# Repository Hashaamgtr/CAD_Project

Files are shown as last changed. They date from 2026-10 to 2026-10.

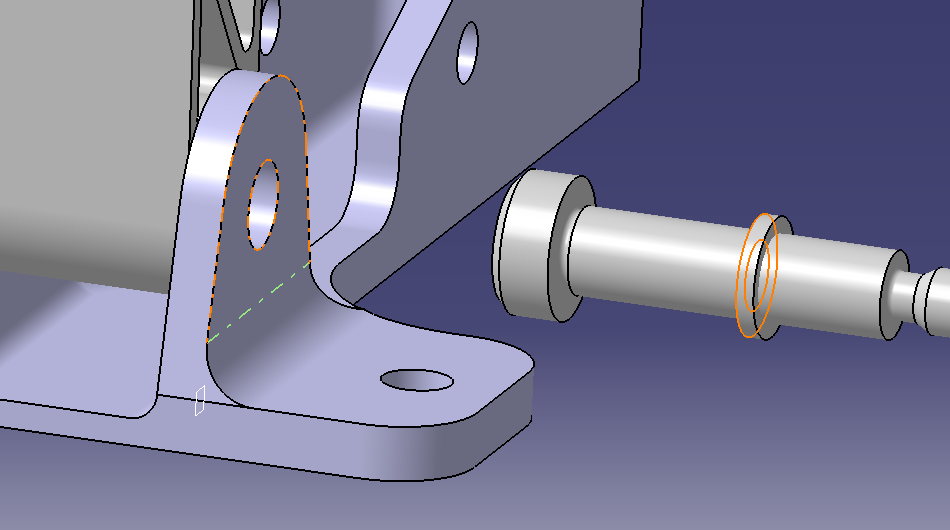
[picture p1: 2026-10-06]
review/05_CATIA_V5_2026_ASSembly_Design/image26.png

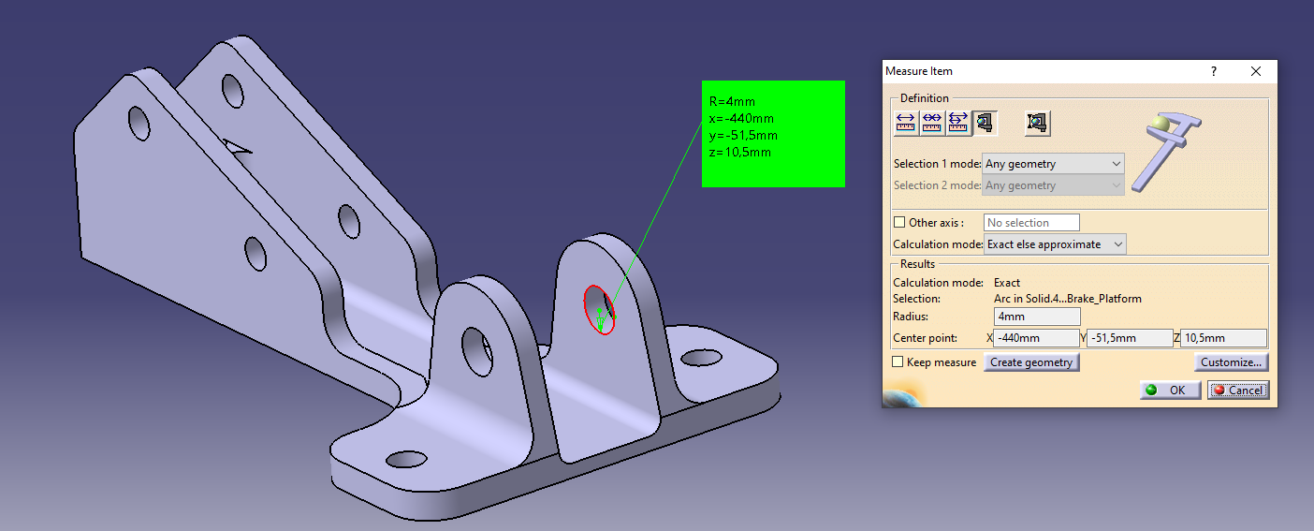
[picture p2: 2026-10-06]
review/05_CATIA_V5_2026_ASSembly_Design/image18.png

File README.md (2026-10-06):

# CATIA brake pedal project

This repository contains the complete unpacked CATIA V5 brake-pedal project handoff plus automation for Presentation 05 and Presentation 06.

## One-click completion on the CATIA Windows machine

Double-click:

`COMPLETE_PROJECT.bat`

The runner:

1. starts CATIA V5 automatically when possible,
2. fixes live-part internal PartNumbers,
3. repairs `Pedal_Body.CATPart` to reference-equivalent geometry while preserving the original live model as a backup,
4. generates `Brake_Pedal_Assembly_05.CATProduct`,
5. generates the full Presentation 06 `Brake_Pedal_Assembly.CATProduct` with the required 45 BOM instances,
6. validates parts/update state/BOM counts,
7. creates `Brake_Pedal_Assembly_Submission.zip`.

Generated reports and screenshots are written to `review/`.

## Main outputs

- `Brake_Pedal_Assembly_05.CATProduct` — Presentation 05 assembly.
- `Brake_Pedal_Assembly.CATProduct` — Presentation 06 final assembly.
- `Brake_Pedal_Assembly_Submission.zip` — packaged native deliverables and dependencies.
- `review/final_validation_report.txt` — structural/update/BOM validation.
- `review/task05_report.txt` and `review/task06_report.txt` — assembly-build reports.
- `review/Task05_Assembly.bmp` and `review/Task06_Assembly.bmp` — generated assembly captures.

## Source structure

- `final_parts/` — latest native live parts.
- `parts/` — imported OEM reference models and Tilton native dependencies.
- `reference_parts/` — supplied STEP reference models.
- `source_copies/` — preserved original work.
- `review/` — tutorial extracts/images, CATIA automation, inspection geometry and reports.
- `live_parts/` and `editable_parts/` — superseded intermediate attempts retained for traceability.

## Presentation 06 BOM

The final assembly builder inserts all 45 required component instances, organized into frame, pivot, Tilton/hydraulics, reservoir, foot-plate, shaft and mounting subproducts.

## Important execution note

Native `.CATPart` and `.CATProduct` generation occurs inside CATIA V5 through its Windows COM/CATScript automation interface. The repository contains the completed automation, but the final native outputs are created when `COMPLETE_PROJECT.bat` is run on the Windows computer where CATIA is installed.

After the automated validation passes, visually inspect the final assembly once in CATIA before external submission, especially for clashes and presentation orientation.

See `HANDOFF_FOR_CHATGPT.md` for recovered dimensions, placement derivations and methodology notes.

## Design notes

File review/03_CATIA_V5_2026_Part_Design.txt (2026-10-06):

slide1.xml: PART DESIGNBY PORSCHE ENGINEERING AND ZEJVY (NOT FILIP)
slide2.xml: PART 4:BRAKE PEDAL SHAFTBY PORSCHE ENGINEERING AND ZEJVY (NOT FILIP)
slide3.xml: PART 4: BRAKE PEDAL SHAFTNowwewill design thebrakepedalshaftforconnectionofhydraulic master cylinders to thebrakepedal body.Youwilllearnfollowingfeatures:ShaftChamferThreadSince this is a very simple part with only a few operations, we will skip copying sketches to GSReferences and perform all solid operations in MAIN.
slide4.xml: PART 4: BRAKE PEDAL SHAFTOpen fileTemplate.CATPart. Saveit as Brake_Pedal_Shaft.CATPart. Rename part as Brake_Pedal_Shaft.Switch to GenerativeShape Design (GSD).CreatethreenewplanesY1+, Y2+ and Y3+. CreateanotherthreeplanesY1-, Y2- and Y3-usingfunctionSymmetry. Youcan use thisfunctionforeasierworkwithsymmetricelements – changeonly reference and symmetric element changes as well.NameReferenceOffsetY1+ZX28Y2+ZX36.75Y3+ZX51.5Y1-ZX (Y1+)0Y2-ZX (Y2+)0Y3-ZX (Y3+)0
slide5.xml: PART 4: BRAKE PEDAL SHAFTCreatenewPositionedSketch (YZ, CenterPoint) in SKE.Use Axisfor axis line. Furtheroperations (Shaft) willautomaticallyrecognize line as axis.Exit thesketch and renameit to YZ_Contour.
slide6.xml: PART 4: BRAKE PEDAL SHAFTCreatenewPositionedSketch (YZ, CenterPoint) in SKE. Use Axis again.Exit thesketch and renameit to Groove.
slide7.xml: PART 4: BRAKE PEDAL SHAFTSet DiWOin MAIN. Switch back to Part Design (PD).Use Shaft 	to create solid fromYZ_Contour.
slide8.xml: PART 4: BRAKE PEDAL SHAFTUse Groove	to create solid fromYZ_Contour.
slide9.xml: PART 4: BRAKE PEDAL SHAFTUse Chamferforedgesshown in picture.Tip: Do NOT forget to renameeveryoperation.
slide10.xml: PART 4: BRAKE PEDAL SHAFTCreatenew plane in PLN. Reference YZ, offset 5 mm. Name itBolt_Hole_Plane.Createnew point withcoordinations [5; 0; 0]. Checkyou use CenterPoint and PartAxisSystem. Name itBolt_Hole_Center.CreateHole, selectBolt_Hole_Center as center, Bolt_Hole_Face as face, diameter 3.2 mm and depth 3 mm. SelectV-Bottomin roll menu ofBottom.
slide11.xml: PART 4: BRAKE PEDAL SHAFTCreatethreads on bothendsoftheshaft. Use Thread. Selectround area ofcylinder as Lateral Face, as Limit Face set theendplaneofthecylinder. SelectMetricThickPitchas Type and M6 as ThreadDefinition. Do thesameforthe second end oftheshaft.Hideeverythingexcept MAIN.Savethe part.Tip:Threadis not visible in model, but in drawingitisvisible. Sometimesthreads in model are marked by color (selectsurfaceofthread and changecolor in Properties > Graphic).
slide12.xml: PART 5: RESERVOIR HOLDERBY PORSCHE ENGINEERING AND ZEJVY (NOT FILIP)
slide13.xml: PART 5:RESERVOIR HOLDERNowwewill design thebrake fluid reservoirsholder.Youwilllearnfollowingfeature:Rib
slide14.xml: PART 5:RESERVOIR HOLDEROpen fileTemplate.CATPart. Saveit as Reservoir_Holder.CATPart. Rename part as Reservoir_Holder.Createsixnewplanes:NameReferenceOffsetY1+ZX10.5Y2+ZX12.5Y1-ZX-10.5Y2-ZX-12.5X+YZ2X-YZ-13CreatetwonewPB. Name themSUB_HOLES and INT_HOLDER. CreateReferences GS in bothofthem.CreatenewPositionedSketch (XY, CenterPoint). Name itXY_Contour.Tip: Youcan use Symmetryforsymmetricplanesifyouwant.
slide15.xml: PART 5:RESERVOIR HOLDERCreatenewPositionedSketch (ZX, CenterPoint). RenameitLead_Line.
slide16.xml: PART 5:RESERVOIR HOLDERCopy XY_Contour and Lead_Linesketcheswith link to INT_HOLDER > References.Use Rib 	to create solid in INT_HOLDER. Set XY_Contour as Profile and Lead_Line as Center curve.
slide17.xml: PART 5:RESERVOIR HOLDERCreatenewPositionedSketch (YZ, CenterPoint). Name itPedal_Holes.CreatenewPositionedSketch (ZX, CenterPoint). Name itReservoir_Hole. Project line fromLead_Linesketch to set constraints.
slide18.xml: PART 5:RESERVOIR HOLDERCopy sketchesPedal_Holes and Reservoir_Hole and Paste with link to References in SUB_HOLES.CreatepadsfromPedal_Holes and Reservoir_Holesketches. Set dimension to 25 mm and checkMirroredextentbox in dialoguewindow.
slide19.xml: PART 5:RESERVOIR HOLDERCopy SUB_HOLES with link to Reservoir_Holder part.Use Removecopied SUB_HOLES fromINT_HOLDER to createholes.Use Chamferforallcorners.Copy INT_HOLDERwith link to Reservoir_Holder part.UseAddcopiedINT_HOLDER to MAIN.HideallelementsexceptMAIN.Savethe part.Tip: Do NOT forget to renameeveryoperation.
slide20.xml: PART DESIGN FINISHED! +5XP!! DESIGN +5Pts!! NEXT: GENERATIVE SHAPE DESIGN

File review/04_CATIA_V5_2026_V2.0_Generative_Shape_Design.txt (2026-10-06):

slide1.xml: GENERATIVE SHAPE DESIGNBY PORSCHE ENGINEERING AND ZEJVY (NOT FILIP)
slide2.xml: PART 6: COOLING DUCTBY PORSCHE ENGINEERING AND ZEJVY (NOT FILIP)
slide3.xml: PART 6:COOLING DUCTNowwewill design an air intakeductfortheaccumulator.Youwilllearnfollowingfeatures:3D curveProjectBlendMulti-selectionsurfaceTrimJoin
slide4.xml: PART 6:COOLING DUCTOpen fileTemplate.CATPart. Saveit as Cooling_Duct.CATPart. Rename part as Cooling_Duct.Change module to GSD.Createthreenewplanes:  CreatenewOGS in WORK. Name Support_Surfaces.CreatenewPositionedSketch(XY, CenterPoint). Name itXY_Curve. Use functionSpline  to createcurve (like in the screenshot)betweenX+ and X-.CreatenewPositionedSketch(ZX, CenterPoint). Name itZX_Curve. Use functionSplineto createcurvebetweenX+ and X-.NameReferenceOffsetY1ZX80X+YZ100X-YZ-100
slide5.xml: PART 6:COOLING DUCTUse ExtrudeonXY_Curve to createside support surface. Name itSide_SupportUse ExtrudeagainonZX_Curvewithsameparameters (except set Directionalong Y-axis). Name itBottom_Support
slide6.xml: PART 6:FOOT PLATECreatenewOGS in SKE. Name itOuter_WFSwitch to FreeStyle(Start>Shape>FreeStyle).ClickQuickCompassOrientationand select XZ planeCreate3D Curvewith 4 controlpoints(Creation type: Controlpoints)Right-clickthestarting point>edit, nowyoucaneditcoordinatesofthe point (start shouldbeoutsidethe support surfacesx˜-150, end point x˜50), Do not clickOKyet.
slide7.xml: PART 6:FOOT PLATEon QuickCompassOrientationselect XY plane and editthe3D curveshape as shown on the screenshot and clickOK.Switch to GSD.Project    3D curveontoBottom_SupportandSide_Support. Name theresultingcurvesBottom_CurveandSide_Curve.
slide8.xml: PART 6:FOOT PLATECreate OGS in WORK, name it Outer_Surface.ExtrudeBottom_Curve by -20 mm alongthe  Z-axis. ExtrudeSide_Curve by 20 mm along the Y-axisUse Blend     to connect these extrusions and create outer surface (Set Tension to 1,2 on both sides)Name it Outer_Surface_1.Tip: Experiment with diferent Tension valuesin the BlendDefinition to observehowthesurface continuity changes
slide9.xml: PART 6:COOLING DUCTDiWOOuter_WF.Extracttheboundryedgeof Outer_Surface_1.Create Positioned Sketch (Y1, CenterPoint), Draw a curve usingSplinesuch that the bottom portion extends below Bottom_support. Name it End_Curve. 
slide10.xml: PART 6:COOLING DUCTDiWOOuter_Surface.ExtrudethisnewSketch by 20mm alongthe Y-axis.Create a Blendbetweentheextrudedsurfaces. Name itOuter_Surface_2SplitOuter_Surface_2 usingSide_Supportand Bottom_Support.
slide11.xml: PART 6:COOLING DUCTJoinSplit.1 and Outer_Surface_1.Use Trim    on Side_Supportand Bottom_Support. Name itSupport_Surface.Use Trimagain on theJoin and Support_Surface. Name itOuter_Skin.
slide12.xml: PART 6:COOLING DUCTCreatenewOGS in SKE. Name itInner_WFCreateanIntersectionbetweenOuter_Skinand X- plane (thiscanalsobe done in sketch)Create a PositionedSketch(X-, CenterPoint), Projecttheperviousintersection line and convertitinto a Construction element.Use Scale   on theprojectedcurve (clickthe element, thenclicknearitsmidpoint, ratio is 0,8) to createinner profile. Name itSection_1
slide13.xml: PART 6:COOLING DUCTCreateanotherPositionedSketch(Y1, CenterPoint), Project End_Curve and applyScalewith ratio 0,7.AddoneHorizontal and oneVertical line to closethe profile. Name itSection_2.
slide14.xml: PART 6:COOLING DUCTUse Spline  to createguidecurveconnectingthecorrespondingendpointsofSections_1 and Section_2. In Spline definitionselectSection_1>shwoparameters> setConstraint type to Fromcurve, right-click on TangentsDir., selectthe X-axis, set Continuity to curvature.SelectSection_2, set TangentsDir. To theY-axis and set Tangent Tensionto 0,7. Name thiscurveGuide_1.
slide15.xml: PART 6:COOLING DUCTRepeatthisprocedure to createtheremainingtwoGuidecurves, Name themGuide_2 and Guide_3.
slide16.xml: PART 6:COOLING DUCTCreatenewOGS in WORK. Name itInner_Surface.CreateMulti-SectionSurface, SelectSection_1 and Section_2, right-clickthe Section_2>replaceclosing point and pickthecornerthatmatchestheonemarked in Section_1.Select Guide_1, Guide_2 and Guide_3 as Guides.Set SectionCouplingto Vertices.Name theresultingsurfaceInner_Surface.
slide17.xml: PART 6:COOLING DUCTSelectEdgeFillet      and apply 5mm radius to allsharpinternalcorners. Name itInner_Skin.Tip: HideInner_WFso youcaneasilyselectthetargetedges.
slide18.xml: PART 6:COOLING DUCTTrimInner_Skinand Outer_Skintogether.Use Boundry     to extractthe open edgeoftheoutersurface.FilltheextractedBoundryto createclosing cap.SplittheFilledsurfacewiththetrimmed skin.Join Split fillsurface and trimmed skin. Name itDuct_Surface.Tip: ClickPreviewbeforefinalizingtheJoinoperation to verifythere are no open edges (thissurafceshouldform a completelyclosedvolume)
slide19.xml: PART 6:COOLING DUCTSwitch to PD and DiWOMAIN.Use ClosedSurface    to create solid fromDuct_Surface.ApplyanEdgeFilletattheDuctinlet (2 mm in theinsideedge, 3mm outside)HideallelementsexceptMAIN.Savethe part.
slide20.xml: GENERATIVE SHAPE DESIGN FINISHED! +5XP!! STYLE +10Pts!!         NEXT: ASSEMBLY DESIGN

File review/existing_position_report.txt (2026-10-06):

Brake_Platform_2 | volume=3.45929323556663E-05 | updated=True | path=C:\Users\Hashaam\Documents\CAD_Project\final_parts\Brake_Platform_2.CATPart
Brake_Pedal_Shaft | volume=6.00639968651768E-06 | updated=True | path=C:\Users\Hashaam\Documents\CAD_Project\final_parts\Brake_Pedal_Shaft.CATPart
Reservoir_Holder | volume=1.29908917589642E-05 | updated=True | path=C:\Users\Hashaam\Documents\CAD_Project\final_parts\Reservoir_Holder.CATPart
Foot_Plate | volume=2.9455816840723E-05 | updated=True | path=C:\Users\Hashaam\Documents\CAD_Project\final_parts\Foot_Plate.CATPart

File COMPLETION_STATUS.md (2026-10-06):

# CAD project completion status

This repository contains the complete unpacked handoff for the CATIA V5 brake-pedal task.

## Repository upload

The original handoff ZIP has been unpacked into the repository. Native CATIA parts/products, supplied STEP references, tutorial extracts, review images, macros and logs are now individually versioned.

## Completed / prepared

- Existing live parts preserved and positioned:
  - `Brake_Platform_2.CATPart`
  - `Brake_Pedal_Shaft.CATPart`
  - `Reservoir_Holder.CATPart`
  - `Foot_Plate.CATPart`
- Live-model builders exist for:
  - `MC_Inlet`
  - `BRK_PRS_Sensor_Connection`
  - `Pedal_Body`
- The live-model builder now assigns the correct internal CATIA `PartNumber`.
- A separate `review/finalize_part_numbers.CATScript` fixes already-generated files without rebuilding geometry.
- Presentation 05 assembly macro is present at `review/assemble05.CATScript`.
- `review/validate_project.CATScript` checks native parts, update state, volume, internal PartNumber and expected assembly files.
- `RUN_FINALIZE.bat` runs the safe automated CATIA steps in sequence.

## Still requires CATIA itself

The project cannot truthfully be marked as a finished submission until the following have been executed and visually/mechanically validated in CATIA V5:

1. Repair `final_parts/Pedal_Body.CATPart`.
   - Current live volume is about 6.15% below the supplied reference.
   - The side reliefs need the missing 6 mm reinforcement regions plus the 1.5 mm floor fillets.
2. Run and inspect `review/assemble05.CATScript`.
3. Build the Presentation 06 final `Brake_Pedal_Assembly.CATProduct` with the complete required BOM.
4. Verify all hydraulic/fastener/reservoir/Tilton placements against the tutorial images and native mating geometry.
5. Run MeasureBetween / MeasureItem / Sectioning and interference checks.
6. Save, close and reopen the final product to verify dependency resolution.
7. Package the final assembly and all referenced native files into one submission ZIP.

## Why these items are not marked complete

This environment does not contain CATIA V5 or Windows COM automation, so it cannot execute CATScript against CATIA, create a trustworthy native `.CATProduct`, or certify interference/assembly mating. Generating a fake binary or claiming unexecuted placements as validated would make the submission unreliable.

See `HANDOFF_FOR_CHATGPT.md` for measured geometry, placement hypotheses, BOM and CATIA API notes.

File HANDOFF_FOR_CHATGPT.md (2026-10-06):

# Handoff for ChatGPT / the next CAD agent

## User objective and restrictions

Complete exercises in presentations 05 (Assembly Design) and 06 (Final Task), using the existing work as the starting point. The user subsequently requested a repository upload and handoff before continuing CAD work. This snapshot is incomplete work, not a finished submission.

Work only in the project folder. Do not modify the original `C:\Users\Hashaam\Desktop\EFORCE` or `C:\Users\Hashaam\Downloads\Newbie task MECH (1)\Newbie task MECH\CATIA_V5_TASK_TUTORIAL` folders. Additional reference models came from `C:\Users\Hashaam\Documents\CATIA_V5_TASK_ASSEMBLY_PARTS`. The project root is `C:\Users\Hashaam\Documents\CAD_Project`.

The user approved continuing the CAD work. No external submission to Discord or the course instructors is authorized. The user authorized uploading all project files to `https://github.com/Hashaamgtr/CAD_Project`.

## Verified state at handoff

All six tutorial text extracts are in `review/`; presentation 05 and 06 images are in the corresponding extracted-media directories. Read the actual tutorial extracts/images before modeling. Do not infer completion from folder names.

`review/position_existing.CATScript` finished successfully. Its report records these project copies as up to date:

| Part | Volume (m3) | Status |
|---|---:|---|
| Brake_Platform_2 | 3.45929323556663E-05 | Existing history preserved; positioned using a new axis-to-axis feature |
| Brake_Pedal_Shaft | 6.00639968651768E-06 | Existing live history, positioned |
| Reservoir_Holder | 1.29908917589642E-05 | MAIN rebuilt as an Add of the existing live INT_Holder; positioned |
| Foot_Plate | 2.9455816840723E-05 | Existing live history; center point Z adjusted |

The platform's original Center Point could not simply be moved: EdgeFillet.1 and later features failed to update. The project copy was restored to original construction coordinates, that point renamed `Construction Center Point`, then the completed MAIN body positioned using `Assembly_Position/CenterPoint` and `Assembly_PAS`. This workaround regenerates, but needs a methodology review against the tutorial. Do not repeat the failed direct move without repairing the original reference chain.

`review/build_corrected.CATScript` finished and saved three additional editable parts in `final_parts/`:

| Part | Measured live volume (m3) | Reference volume (m3) | Remaining caveat |
|---|---:|---:|---|
| MC_Inlet | 1.88124162882973E-06 | 1.88124052058092E-06 | Near-identical volume; still verify shape, dimensions and placement |
| BRK_PRS_Sensor_Connection | 2.57117815120888E-06 | 2.57117897136689E-06 | Near-identical volume; still verify shape, dimensions and placement |
| Pedal_Body | 3.68955817142926E-05 | 3.93124069892468E-05 | Incorrect relief details; approximately 6.15% too little material |

The pedal has real pad/pocket/sketch history, both side reliefs, pivot/shaft bores, mounting bores and a final PAS positioning feature. It is NOT geometrically finished. The models have editable sketch geometry but need constraint and naming review; do not call their sketches fully constrained. Some new root part names may still be generic Part numbers.

Imported OEM files are saved in `parts/` as `*_Reference.CATPart`. `Tilton_Set_Reference.CATProduct` has four native child CATParts that must travel with it. Preserve the entire folder when relocating. The source STEP files are in `reference_parts/`.

No presentation 05 assembly has been generated by this work yet. `review/assemble05.CATScript` is prepared but **UNRUN / UNTESTED**. No complete presentation 06 assembly or submission ZIP exists. The user's original Documents assembly, if open in CATIA, is unrelated to a completed project output and must not be saved accidentally.

## Resume sequence

1. Open project copies in CATIA, check paths and update status. Review `existing_position_report.txt`, `live_build_log.txt`, and `source_integrity_verified.json`.
2. Finish presentation 05 first. Inspect and run `review/assemble05.CATScript`, repair any API or geometry failures, and save `Brake_Pedal_Assembly_05.CATProduct` in the project root. The macro should create an imported pedal with CAS orientation correction and PAS placement, then insert the platform, pedal, fitted bolt, washer 8, washer 6 and nut M6. Verify all six components and mating geometry visually and by measurement. These initial placements are calculated, not validated assembly results.
3. Correct the editable Pedal_Body for presentation 06. Add the missing reinforcement material around mounting bores and proper relief-floor fillets; compare its shape to the reference, not just its volume. Existing side reliefs use 9 mm depth everywhere, whereas reference pockets have both 9 mm and 6 mm depths and 1.5 mm floor fillets. Prefer editing feature history; do not replace this required live part with an imported solid.
4. Assemble presentation 06 with the live pedal replacing the imported pedal. Organize sensible subproducts, such as pivot hardware, hydraulic/Tilton components, reservoir assembly, and foot plate hardware. Preserve methodology: internal PAS positioning for modeled parts, no unnecessary inter-part links or assembly constraints. Numeric rigid placements are equivalent to Snap for allowed hardware, but must be checked.
5. Validate the complete bill of materials, coincident axes, washer seating, mounting holes, overall dimensions and interferences. Update every part/product. Reopen the saved product to test dependencies. Ensure links resolve within the project, not EFORCE or the user's other Documents files.
6. Create a clean submission directory and ZIP containing the final assembly, all referenced native parts/subassemblies, and a concise validation note. Keep intermediate drafts out of the submission, but retain them in this repository as requested. Never claim complete until saved/reopened and checked.

## Presentation 05 placement targets (mm)

- Platform CenterPoint: (-440, -90.5, -8.5).
- Pedal pivot: (-440, -61.5, 10.5).
- Imported pedal orientation: tutorial source axis X=(0,-1,0), Y=(1,0,0), transformed to default CAS. Equivalent geometry mapping: original (x,y,z) -> (-y,x,z) + pivot.
- Pivot bracket outer faces Y=-75.5 and -47.5; inner faces Y=-71.5 and -51.5.
- Fitted bolt head seat Y=-77.1, local +Z toward world -Y (shaft extends toward +Y).
- Washer 8: Y=-77.1 to -75.5. Washer 6: Y=-47.5 to -45.9.
- Nut M6 first face Y=-45.9, length toward +Y. Verify actual native part axes and seat geometry before finalizing.

## Presentation 06 bill of materials

| Item | Quantity | Model type |
|---|---:|---|
| Pedal platform | 1 | live |
| Pedal body | 1 | live |
| Master cylinder inlet | 2 | live |
| Brake pressure sensor connection | 2 | live |
| Brake pedal shaft | 1 | live |
| Foot plate | 1 | live |
| Reservoir holder | 1 | live |
| Brake pressure sensor | 2 | imported |
| Tilton set | 1 | imported subassembly |
| Banjo adapter | 2 | imported |
| Reservoir | 2 | imported |
| Nut M5 | 2 | imported |
| Nut M6 | 4 | imported |
| Reservoir distance | 2 | imported |
| Copper washer | 6 | imported |
| Washer 5 | 4 | imported |
| Washer 6 | 3 | imported |
| Washer 8 | 1 | imported |
| Bolt M5x40 | 2 | imported |
| Fitted bolt M6 8x30 | 1 | imported |
| Low head cap screw M4x20 | 2 | imported |
| Hex bolt M6x60 | 1 | imported |
| Setscrew M4x8 | 1 | imported |

## Measured geometry and working placement hypotheses

Distinguish measured source geometry from the unverified assembly hypotheses below.

- Shaft center is positioned at (-440,-61.5,183.5); shaft local axis is Y, total length 103 mm.
- Foot plate lower mounting hole originally (-423,-61.5,162); shifted Z to 162.938941558. Its upper hole is 34 mm above. Reference pedal holes are at old Z=152.438941558 and 186.440654138; after pivot placement their world Z values differ by 34.00171258 mm. Resolve/document the roughly 0.001713 mm pitch mismatch instead of silently declaring exact coincidence.
- Holder is translated to (-425,-61.5,162.938941558). Its top cross-bolt center becomes (-461.5,-61.5,253.3863380046).
- Reservoir source lug axis is (-28,0,37.5). Tentative reservoir rotation is 180 degrees about Z, with cup origins (-489.5,-39,215.8863380046) and (-489.5,-84,215.8863380046). Check against tutorial images and actual clearances.
- Reservoir spacers are 9 mm long along source X (from -4.5 to +4.5). Tentatively orient along world Y, between holder and reservoir lugs.
- Foot plate low-head screws should enter from world X=-420, shanks toward -X, at the two plate hole heights. Source low-head screw shank is along +X, 0..20; head is at negative X.
- Tilton product native transforms are in its STEP file. Master-cylinder component origins: (10.6045,102.679533842,153.373986197) and (-55.4355,102.679533842,153.373986197). Source component X=(0,0.547139628895,-0.837041352917), Z=(0,0.837041352917,0.547139628895), Y=(-1,0,0).
- Working Tilton placement hypothesis: root X -> world +Y, root Y -> world -X, root Z -> world +Z. Source shaft line estimated using component local X=-59.2809542156; source shaft midpoint X=-22.4155. Derive translation so shaft midpoint becomes (-440,-61.5,183.5). VERIFY with the real bearing axis and platform mounts first; this has not been assembled or validated.
- Master ports in component local coordinates: inlet around (-11.3765542156,0,27.051), larger boss around Z=31.75; outlet around (-44.9045542156,0,26.035), boss Z=29.21. Port axes along local Z. Confirm seating surfaces and thread depths.
- MC inlet source axis is +Z: insertion 0..10, hex 10..14, hose barb 14..22.5. Copper washer thickness 1 mm must be accounted for at the seat.
- Sensor connection source axis is +Y: female opening Y=0, shoulder Y=16, stem ends Y=32.2. Banjo eye source axis is Z, thickness 9 mm, hole radius 5. Tentative stack: washer 16..17, banjo 17..26, washer 26..27, then threaded engagement. Verify against source recess and radial port at Y=21.1.
- Pressure sensor source axis is Z, thread tip near Z=18.4, wire end near -22. Orient thread into the connection's female opening.

## Pedal reconstruction clues

The STEP has analytical LINE/CIRCLE boundaries. `build_corrected.CATScript` contains the recovered outer profile and seven relief profiles. Source outer face bound 340, relief bounds 414,464,514,564,606,656,706 were used. Both side pockets are currently depth 9, leaving 2 mm web.

Reference floor regions include X=+/-1 (9 mm pocket depth) and X=+/-4 (6 mm depth). The thicker areas around the two front mounting bores need to be recreated. Reference negative-side planar face IDs/ranges:

- 8462: X=-1, Y -11.5..2.50447, Z 157.7445..177.5103.
- 8538: X=-4, Y -11.5..-1.0835, Z 180.5103..197.82718.
- 8637: X=-4, Y -11.5..-2.85758, Z 141.8257..154.8886.
- 8840: X=-4, Y -0.18738..5.5, Z 149.657..158.254.
- Other X=-1 floors: 8681,8711,8731,8749,8779,8876.
- Positive-side equivalents: 8910,8985,9039,9086,9157,9275,9299,9325,9343,9367.

These entity IDs apply to the original STEP, not later CATIA exports. Inspect actual topology to select fillet edges reliably. Volume alone is insufficient verification.

## CATIA automation notes

Installed application: `C:\Program Files (x86)\Dassault Systemes\B21\intel_a\code\bin\CNEXT.exe` (32-bit CATIA V5 B21).

Use the existing 32-bit VBScript runner, which invokes an internal CATScript through CATIA.SystemService.ExecuteScript:

```powershell
& 'C:\Windows\SysWOW64\cscript.exe' //Nologo 'C:\Users\Hashaam\Documents\CAD_Project\review\run_macro.vbs' assemble05.CATScript
```

The host must have CATIA running. In Codex the COM calls required execution outside the sandbox. External PowerShell COM returned misleading null/E_FAIL results; 32-bit cscript plus internal CATScript worked. Do not run multiple CATIA macros concurrently. Use CRLF ASCII CATScript files headed `Language="VBSCRIPT"`.

Important API observations from this session:

- `AddNewAxisToAxis2` can create the feature yet return Nothing. Call it, then get `main.Shapes.Item(main.Shapes.Count)`, then update.
- CATIA reference property assignments such as `axis.OriginPoint=part.CreateReferenceFromObject(point)` and `part.InWorkObject=main` use no `Set` in these working macros.
- Append the support point and update before using it as a reference. Plane.SetReferencePoint can override the equation offset; a support point at the intended origin is essential.
- Set AxisSystem.XAxisType=1 and YAxisType=1 before PutXAxis/PutYAxis.
- Negative sketch axis directions were normalized unexpectedly by CATIA. Corrected pedal sketches use positive YZ axes on both sides, with Pocket.DirectionOrientation controlling cut direction. Check material actually removed.
- SaveAs can fail if the destination is already open. Avoid rerunning the builders over existing outputs without managing open documents and preserving the latest copies.
- STEP overwrite dialogs may block a macro even with DisplayFileAlerts=False. Use unique export names or manage only generated inspection exports explicitly. Check the runner completion and report file before another macro.
- The user's original `Documents\Brake_Pedal_Assembly.CATProduct` may be open. Do not save it or assume it is this task's completed assembly. Native UUID/link resolution can reuse open documents; always inspect FullName before any save.
- Native UI work in this environment used the computer-use skill with `@oai/sky` through node_repl. Follow that skill if needed. Screenshots sometimes captured another foreground app, so do not act on a mismatched image.

## Files to use and avoid

Use `final_parts/` as the starting native work, with the pedal caveat above. `parts/` is the OEM library. `build_corrected.CATScript` is the newest builder. `position_existing.CATScript` is a completed one-shot positioning macro; it now expects an open platform document and is not a generally idempotent rebuild script.

`build_live.CATScript`, `live_helpers.txt`, `repair_pedal.CATScript`, `live_parts/`, and `editable_parts/` are superseded attempts. `review/pedal_current.stp` is an old partial state. Old BMPs can show the wrong active document. Treat logs and native models as stronger evidence than an arbitrary screenshot.

All current work is saved; no CATIA macro remains running at this handoff. EFORCE/tutorial SHA-256 verification is recorded separately. Recheck those files before final delivery if working on this same machine.

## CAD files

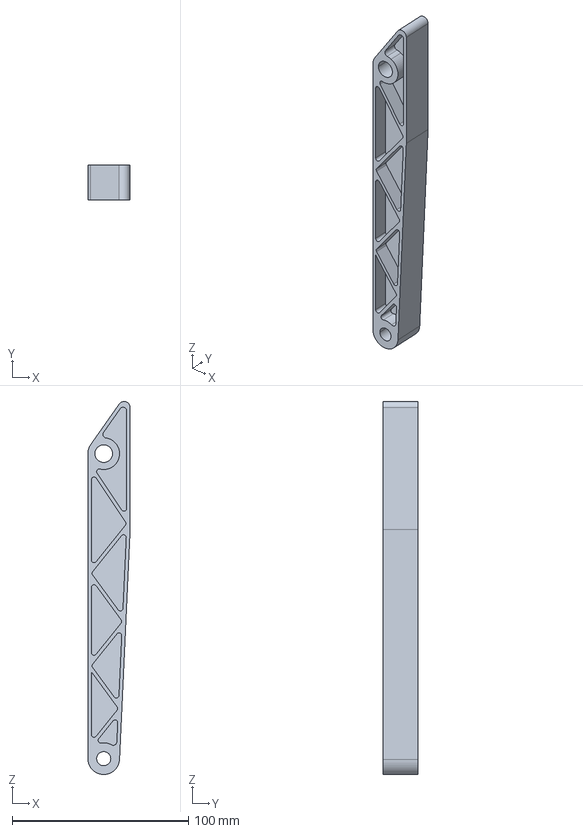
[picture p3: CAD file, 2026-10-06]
review/Pedal_Body_live.stp
24.0 x 20.0 x 211.6 mm

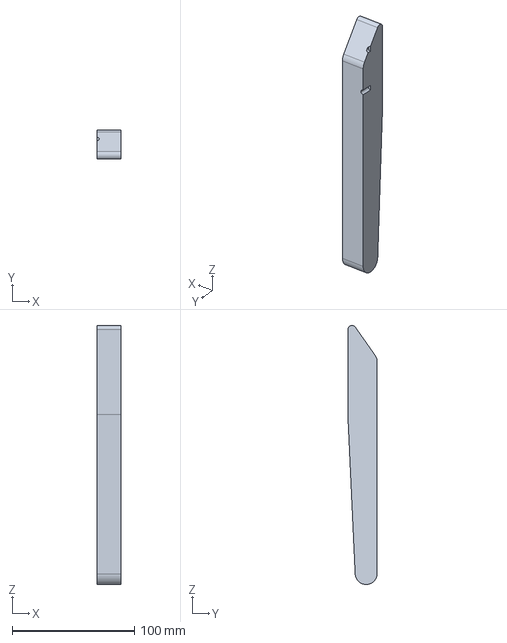
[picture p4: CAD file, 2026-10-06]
review/pedal_current.stp
20.0 x 24.0 x 211.6 mm

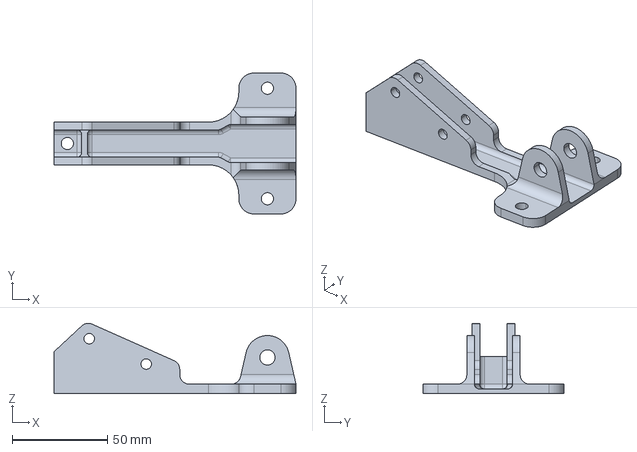
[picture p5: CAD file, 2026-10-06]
review/Part 2&3.stp
127.0 x 74.0 x 36.9 mm

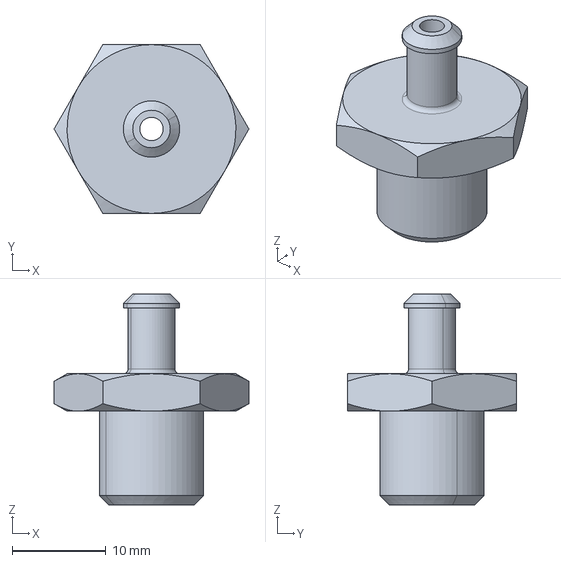
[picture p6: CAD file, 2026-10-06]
review/MC_Inlet_live.stp
20.8 x 18.0 x 22.5 mm

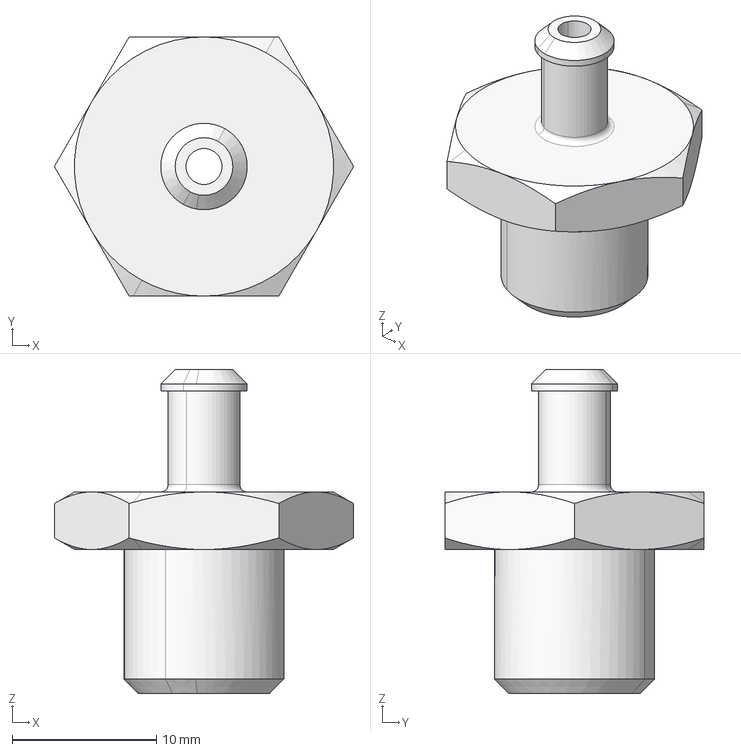
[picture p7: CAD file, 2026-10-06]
reference_parts/MC_Inlet.stp
20.8 x 18.0 x 22.5 mm

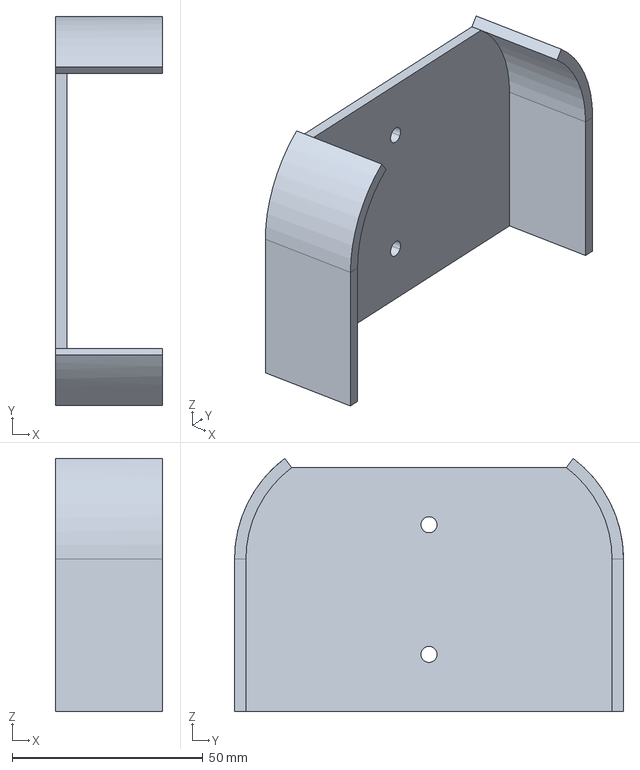
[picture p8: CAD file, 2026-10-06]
review/Foot_Plate_positioned.stp
28.0 x 102.0 x 66.4 mm

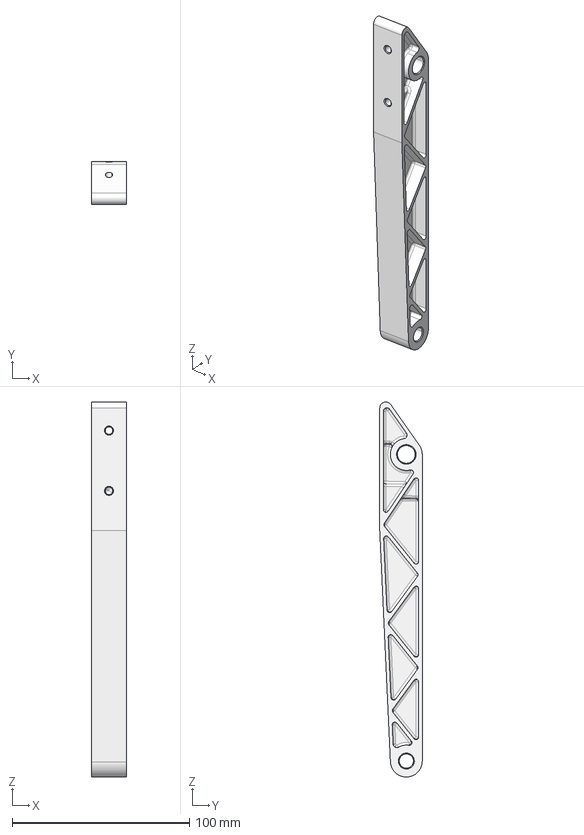
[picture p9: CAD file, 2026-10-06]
reference_parts/Pedal_Body.stp
20.0 x 24.0 x 211.6 mm

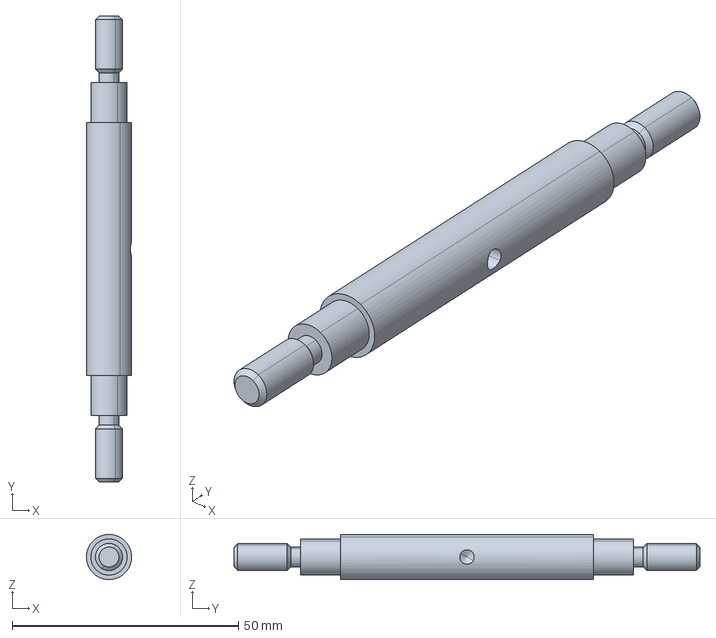
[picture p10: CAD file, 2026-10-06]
review/Brake_Pedal_Shaft_positioned.stp
10.00 x 103.0 x 10.00 mm

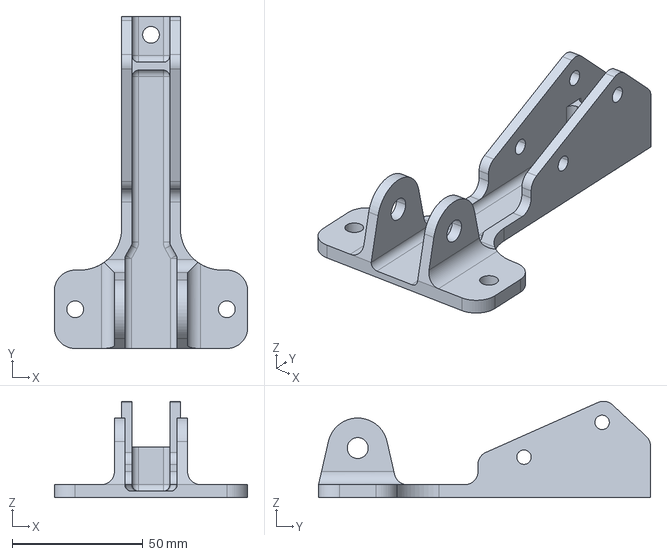
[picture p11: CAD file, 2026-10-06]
review/Part1.stp
74.0 x 127.0 x 36.9 mm

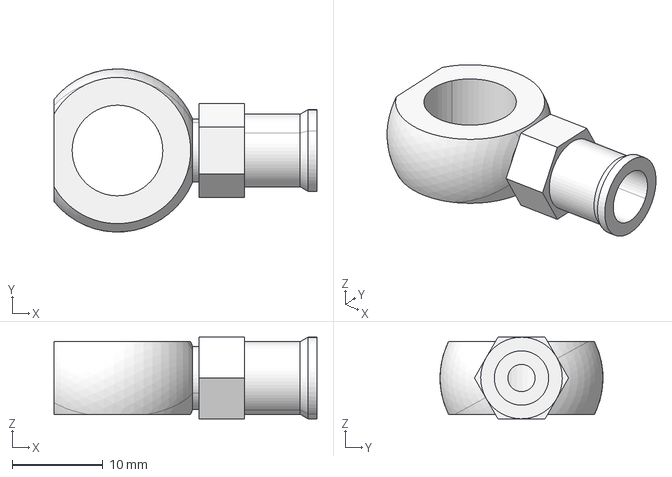
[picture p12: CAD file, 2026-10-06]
reference_parts/Banjo.stp
29.0 x 18.0 x 9.00 mm

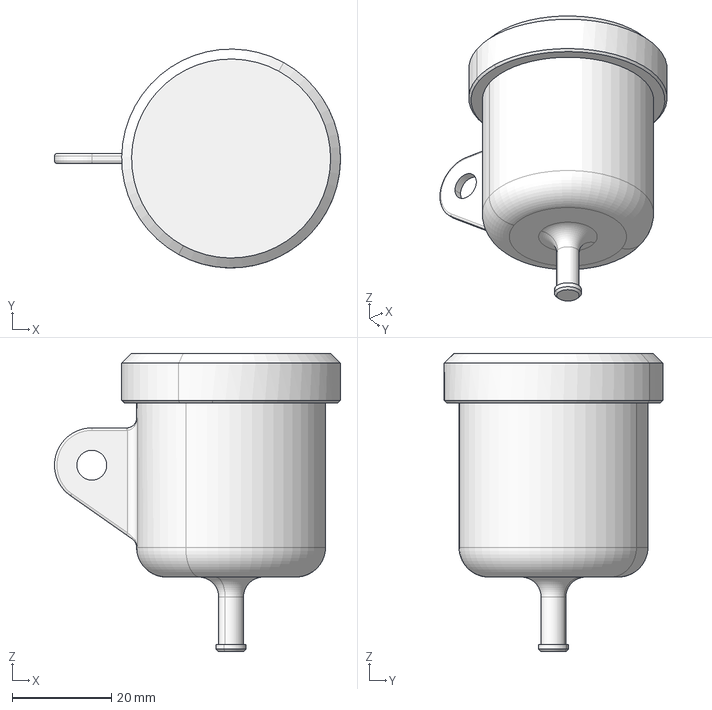
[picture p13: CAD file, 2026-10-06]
reference_parts/Reservoir.stp
57.5 x 44.0 x 60.0 mm

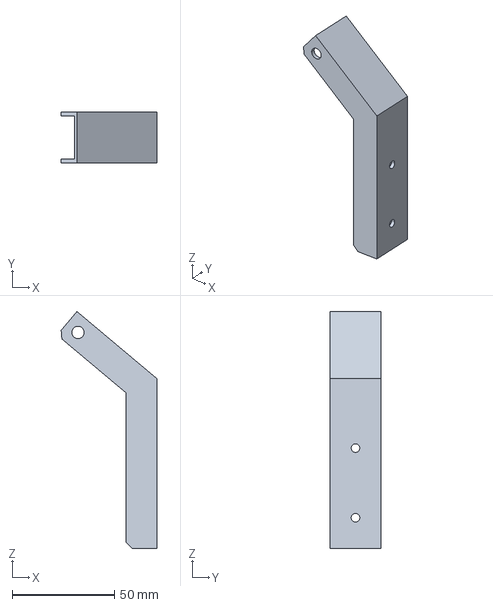
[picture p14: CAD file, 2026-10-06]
review/Reservoir_Holderr.stp
46.7 x 25.0 x 115.7 mm

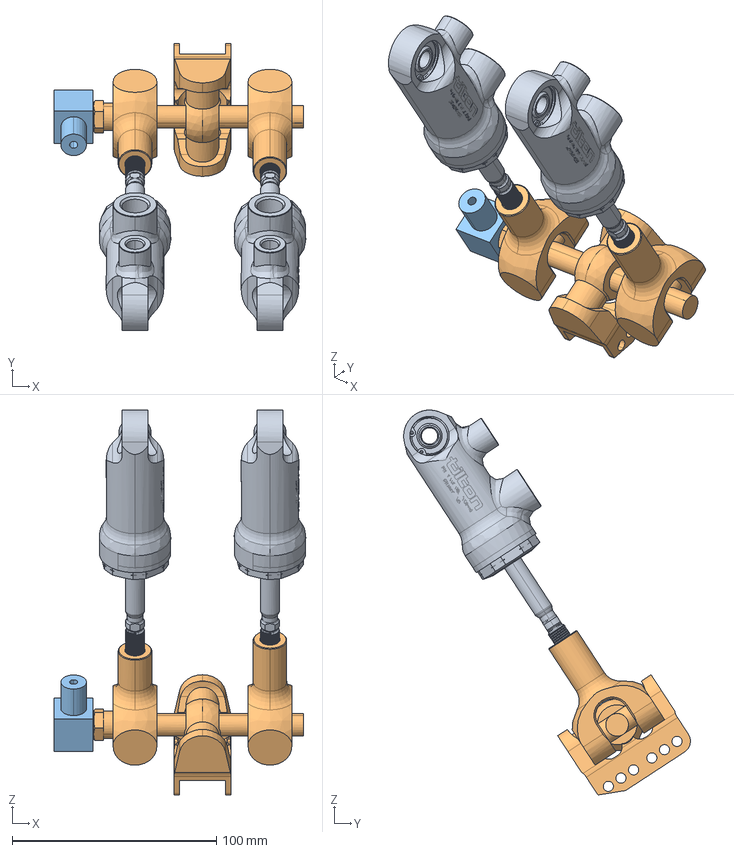
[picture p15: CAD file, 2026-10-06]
reference_parts/Tilton_Set.stp
123.1 x 140.3 x 188.4 mm
Brake_bias_90_degree_coupler

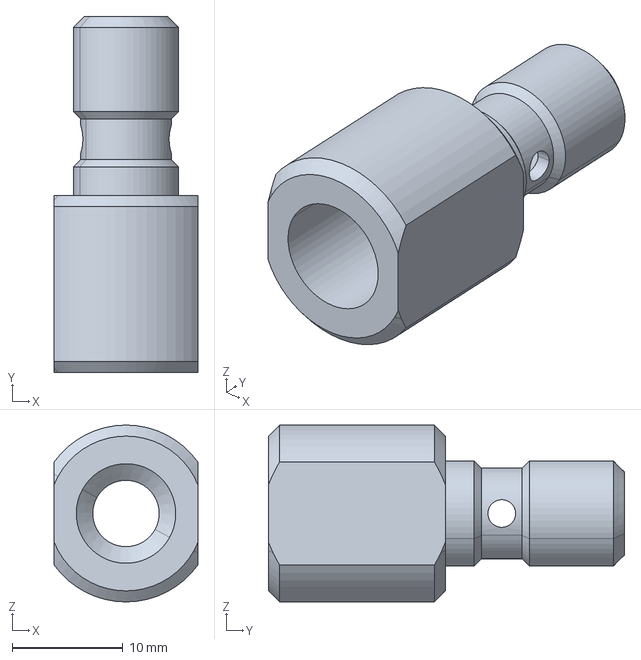
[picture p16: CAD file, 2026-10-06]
review/BRK_PRS_Sensor_Connection_live.stp
13.0 x 32.2 x 16.0 mm

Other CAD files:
review/Foot_Plate.stp
review/Brake_Pedal_Shaft.stp
review/Reservoir_Holder_positioned.stp
reference_parts/Low_Head_M4x20.stp
editable_parts/BRK_PRS_Sensor_Connection.CATPart
editable_parts/MC_Inlet.CATPart
editable_parts/Pedal_Body.CATPart
final_parts/BRK_PRS_Sensor_Connection.CATPart
final_parts/Brake_Pedal_Shaft.CATPart
final_parts/Brake_Platform_2.CATPart
final_parts/Foot_Plate.CATPart
final_parts/MC_Inlet.CATPart
final_parts/Pedal_Body.CATPart
final_parts/Reservoir_Holder.CATPart
live_parts/BRK_PRS_Sensor_Connection.CATPart
live_parts/MC_Inlet.CATPart
live_parts/Pedal_Body.CATPart
parts/BRK_PRS_Sensor_Connection_Reference.CATPart
parts/BRK_PRS_Sensor_Reference.CATPart
parts/Banjo_Reference.CATPart
parts/Bolt_M5x40_Reference.CATPart
parts/Copper_Washer_Reference.CATPart
parts/Fitted_Bolt_M6_8x30_Reference.CATPart
parts/Hex_Bolt_M6x60_Reference.CATPart
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

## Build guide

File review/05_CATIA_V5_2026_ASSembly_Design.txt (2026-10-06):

slide1.xml: ASSEMBLY DESIGNBY PORSCHE ENGINEERING AND ZEJVY (NOT FILIP)
slide2.xml: IMPORTBY PORSCHE ENGINEERING AND ZEJVY (NOT FILIP)
slide3.xml: PART 8: IMPORTNowweneed to make assemblyofbrakepedal. It containsseveralparts. Wealreadydesignedplatform, shaft, reservoirholder and foot plate. But wealsoneed OEM parts as fasteners, hydraulic master cylindersorbrakepressuresensors. Youwilllearnfollowingfeatures:ImportCreatecorrect PAS forimportedpartsOEM parts are usuallydeliveredfrommanufacturer as deadmodels.
slide4.xml: PART 8: IMPORTCreatenewproduct and nameitBrake_Pedal_Assembly(File > New > Product).Checkyouwork in AssemblyDesign module.SelectInsert > ExistingComponentand click on Brake_Pedal_Assemblyin model tree. ChooseBrake_Platform_2.CATPartfromyourfolder.Insert Pedal_Body.stpfromParts > Dead_Modelsfolderattached to thecourse zip file.Reminder: These operationssometimescrash. It mighttakemultipleatemptsbeforeitisright. Dontforget to saveyourprogress. Welcome to CAD systems.
slide5.xml: PART 8: IMPORTSelectpedal body part and switch to PD (by double click on part youautomatically switch to PD orGSD). CreatenewOGSnamedPositionand CAS.In CAS createnew point withcoordinates [0; 0; 0]. Reference  Name itOrigin.Createnew axis systemnamedAxisSystem0. Set origin to Origin and all axis default. CheckUnderthe Axis Systems node. Systemshouldbeidentical to thecompass in top rightcorner.
slide6.xml: PART 8: IMPORTCreatenew axis systemwithorigin in Origin. Do NOT checkUnderthe Axis Systems node. Name itAxisSystem1. Rotateit so the x, y, z axis followscorrectdirectiontowardsPB withdead solid (in this case Brake_pedal body). In this case thebestoptionis to use coordinates:X axis: [0; -1; 0]Y axis: [1; 0; 0]Z axis: default [0; 0; 0]
slide7.xml: PART 8: IMPORTSet DiWO to Brake_pedal body. UseAxisToAxisto correctpositionofimported part towardsCAS.Hide all planes and axis systems.Save the part.
slide8.xml: PART 8: IMPORTComment: Wereached default positionforfurthermanipulation. It isbetter to correcttheorientationofimported model first and thenmoveitanywhereelse.Comment: Positioning ofimported part canbeoftentricky. Youneed to chooseCenterPointwisely and becarefulwithcorrectusingof axis systems. Originisabsolutecoordinateofthe car [0; 0; 0]. CAS isalways on thesameposition. OnlyPASismoved.Tip: Forrotationof axis systemyoucanalso use Axis RotationorEuler Angles.  To understandEuler Angleswerecommendtutorials on YouTube.
slide9.xml: POSITIONINGBY PORSCHE ENGINEERING AND ZEJVY (NOT FILIP)
slide10.xml: PART 9: POSITIONINGNowweneed to set allparts to correctposition.Youwilllearnfollowingfeatures:Set positionusing PASSnapWeknowtheexactpositionof center ofleftrear hole ofpedalplatform in thewhole model car. It is [-440; -90.5; -8.5].
slide11.xml: PART 9: POSITIONINGHideallpartsexceptBrake_Platform.Show PASofBrake_Platform. Show alsoitsCAS (xy plane, yz plane, zx plane). ChangecoordinatesofCenterPoint to [-440; -90.5; -8.5]. Platformwillmove to correctposition – everythingmovesexceptCAS.Hideallplanes.
slide12.xml: PART 9: POSITIONINGMeasurepositionof center ofinner-sidecircleofpedalholderson theplatform (bothsides). Themidpointbetween these circlecentersdefinestheCenterPointofpedal body. 
slide13.xml: PART 9: POSITIONINGCreateCenterPoint in Positionof part Pedal_Bodywithcoordinates [0; 0; 0].Set DiWOin Brake_pedalPB and use Translate.Hint: Translateisusuallyusedwithdeadbodiesitisrecomended to positionpartsusing PAS PAS = Part axis system -> isconected to part and othergeometricalelementsCAS = Car axis system -> reference for PAS 
slide14.xml: PART 9: POSITIONINGImport Fitted_Bolt_M6_8x30.stp, Nut_M6.stp, Washer_8.stp and Washer_6.stp .Use Snap 	to movefasteners to correctposition. Clickfirst on part youwant to move, then on the reference part - click on middlecylinderofthefittedbolt and then to the hole in pedalplatform. Click on emptyspace to finishtheoperation.Tip:Alwayscheckthatyouhaveselected instance thatisonlyone level higher in model tree, otherwiseyouwillmovewithwholeassemblies.
slide15.xml: PART 9: POSITIONINGUse SnapagainthesamewayforWasher 6 and Washer 8.Use Snapagain and click on one plane ofWasher 8 and then on leftholderoftheplatform. Use thesameforWasher 6.Tip:Watchclosely, whichplanes are selected on thepictures – ifyouselecttheotherone, thewasherwillmoveinsidetheplatform.
slide16.xml: PART 9: POSITIONINGUse Snapagainthesamewayforfittedbolt.Place Nut_M6 to thecorrentposition.
slide17.xml: PART 9: POSITIONINGComment: Use Snaponlyforsmallparts such as fastenersorinserts (tensorhundredsparts). Snapdoes NOT create any link, so itis not slowingdownthe model. ThedownsideofSnapisthatthe part does not contain any informationaboutitscorrectposition. Ifsomeoneaccidentlymovethe part youhave to findthepositionagain (sometimesitisproblembecause part does not always has exact reference point in the car).Tip:sometimesitisfaster to snappartsinto a corectpositionor use otherforbidenfunctionsfor fast iterating but final model shouldbeacording to methodologyForexamplehavingkinematic model ofanassemblywhichis not in themain model of car thenduplicatingit and removingtheconections
slide18.xml: ASSEMBLY DESIGN FINISHED! +5XP!! DESIGN +5Pts!!NEXT: FINAL TASK

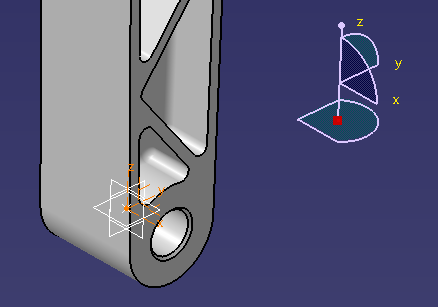
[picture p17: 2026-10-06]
review/05_CATIA_V5_2026_ASSembly_Design/image11.png

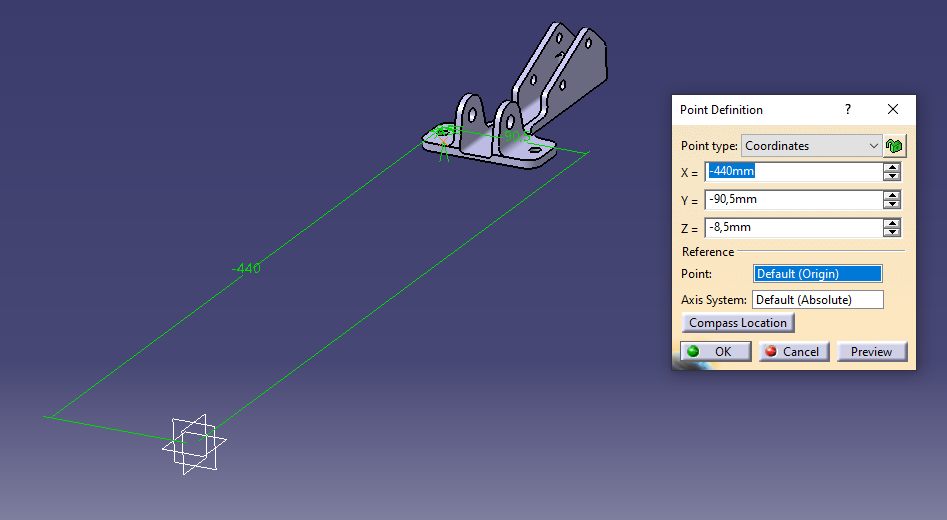
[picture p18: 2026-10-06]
review/05_CATIA_V5_2026_ASSembly_Design/image17.png

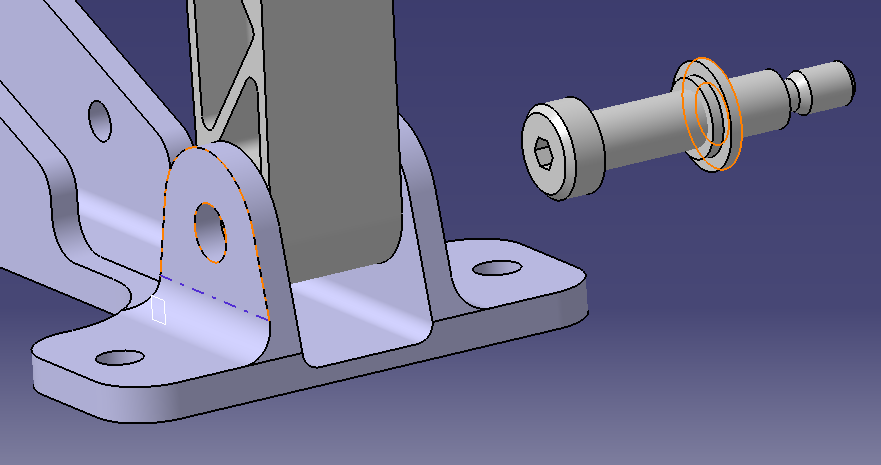
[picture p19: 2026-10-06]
review/05_CATIA_V5_2026_ASSembly_Design/image25.png

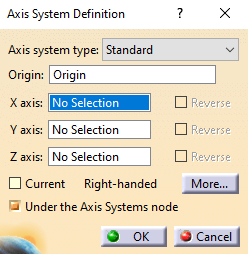
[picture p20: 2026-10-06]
review/05_CATIA_V5_2026_ASSembly_Design/image10.png

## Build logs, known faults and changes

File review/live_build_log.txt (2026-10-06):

START MC_Inlet
Turned_Inlet
Hexagon_AF18
SAVED MC_Inlet VOLUME_M3=2.06009965031536E-06 UP_TO_DATE=True
START BRK_PRS_Sensor_Connection
Turned_Sensor_Connection
Flats_AF13
Radial_Fluid_Port_D2_5
SAVED BRK_PRS_Sensor_Connection VOLUME_M3=2.72041256550065E-06 UP_TO_DATE=True
START Pedal_Body
Pedal_Blank_20
Relief_Right_6
Relief_Left_6
Through_Bores_D8_D10
Mounting_Bores_D4_134
START MC_Inlet
Turned_Inlet
Hexagon_AF18
SAVED MC_Inlet VOLUME_M3=1.8824556362956E-06 UP_TO_DATE=True
START BRK_PRS_Sensor_Connection
Turned_Sensor_Connection
Flats_AF13
Radial_Fluid_Port_D2_5
SAVED BRK_PRS_Sensor_Connection VOLUME_M3=2.57117815120888E-06 UP_TO_DATE=True
START Pedal_Body
Pedal_Blank_20
Relief_Right_6
Relief_Left_6
Through_Bores_D8_D10
Mounting_Bores_D4_134
SAVED Pedal_Body VOLUME_M3=6.82442321958942E-05 UP_TO_DATE=True
START MC_Inlet
Turned_Inlet
Hexagon_AF18
SAVED MC_Inlet VOLUME_M3=1.88124162882973E-06 UP_TO_DATE=True
START BRK_PRS_Sensor_Connection
Turned_Sensor_Connection
Flats_AF13
Radial_Fluid_Port_D2_5
SAVED BRK_PRS_Sensor_Connection VOLUME_M3=2.57117815120888E-06 UP_TO_DATE=True
START Pedal_Body
Pedal_Blank_20
Relief_Right_9
Relief_Left_9
Through_Bores_D8_D10
Mounting_Bores_D4_134
SAVED Pedal_Body VOLUME_M3=3.68955817142926E-05 UP_TO_DATE=True

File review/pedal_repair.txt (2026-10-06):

Left direction 1,0,0 orientation 1
Sketch axes -10,0,0,0,1,0,0,0,-1
Volume 6.82442321958942E-05

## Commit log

2026-10-06 Unpack CAD project handoff
    [BRK_PRS_Sensor.stp, BRK_PRS_Sensor_Connection.CATPart, BRK_PRS_Sensor_Connection.stp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]
2026-10-06 Add complete Presentation 06 assembly builder
2026-10-06 Complete and harden Presentation 05 assembly builder
2026-10-06 Make CATIA macro runner portable and auto-attach
2026-10-06 Validate Presentation 05 and final 45-item BOM
2026-10-06 Align Tilton and final hardware to tutorial mounting holes
2026-10-06 Make final assembly builder repeatable
